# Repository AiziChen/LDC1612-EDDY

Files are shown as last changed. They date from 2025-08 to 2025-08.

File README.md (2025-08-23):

# LDC1612 Eddy coil

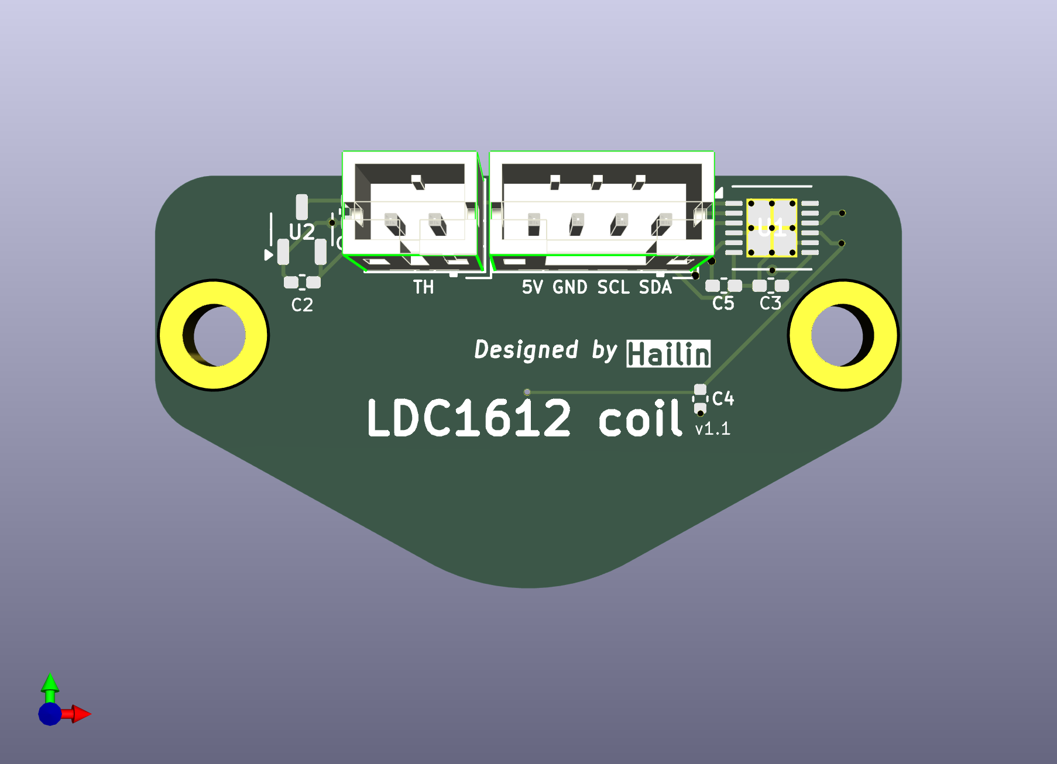
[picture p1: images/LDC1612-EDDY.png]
PCB foreground

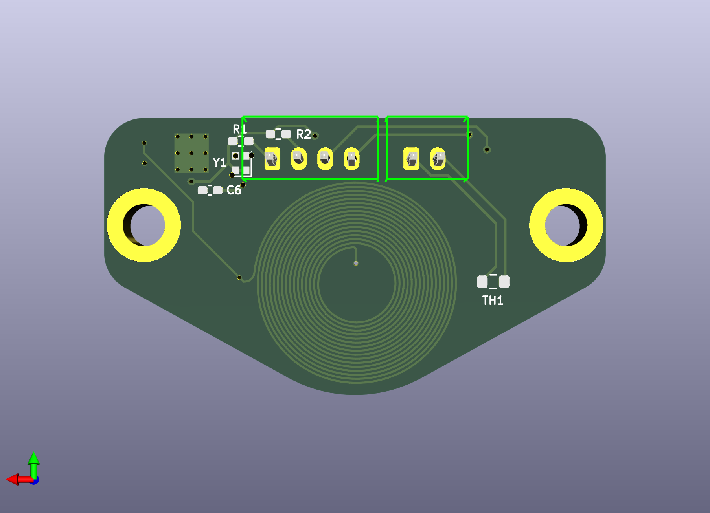
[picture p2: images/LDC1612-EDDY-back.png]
PCB background


A surface scanner for Klipper firmware [Eddy current probe](https://www.klipper3d.org/Eddy_Probe.html?h=eddy#eddy-current-inductive-probe) to provide very fast and high accuracy surface scanning.

## Features

* Similar to [Beacon revH](https://beacon3d.com/product/beacon-h/), but open source.
* Simple, no microcontroller, only LDC1612 chip inside.
* Connection stable, only support I2C connecting, but it is stable than via USB or CAN through an another MCU.
* Has an NTC thermistor to support coil temparature detect.

## How to use

This is a Kicad project, if you want to modify this project, you need to clone it, then download and install [Kicad](https://www.kicad.org/download/) to open.

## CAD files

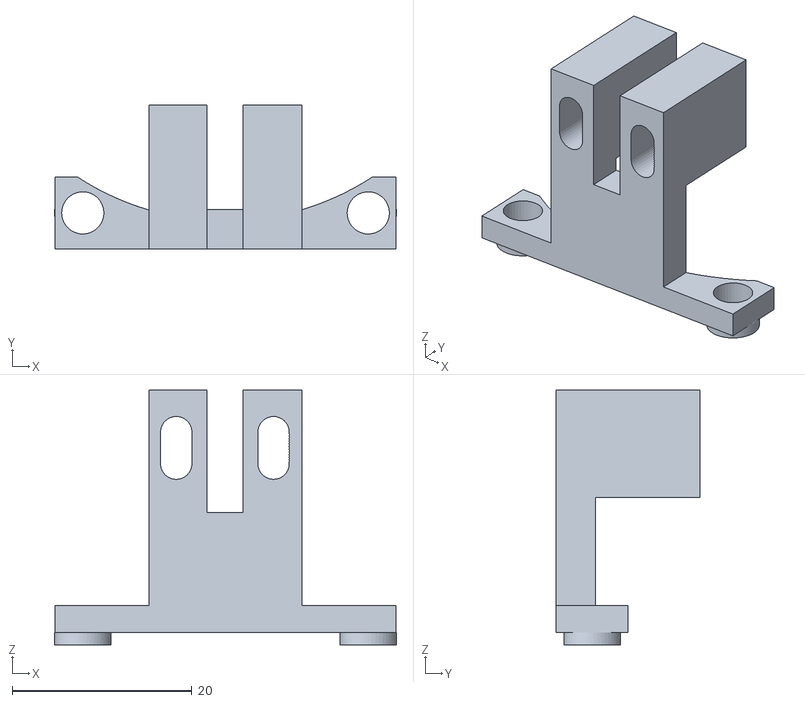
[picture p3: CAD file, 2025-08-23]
STL/LDC1612-eddy-coil-Mount [Voron-Carriage] - v1.0.2.stl
38.1 x 16.0 x 28.4

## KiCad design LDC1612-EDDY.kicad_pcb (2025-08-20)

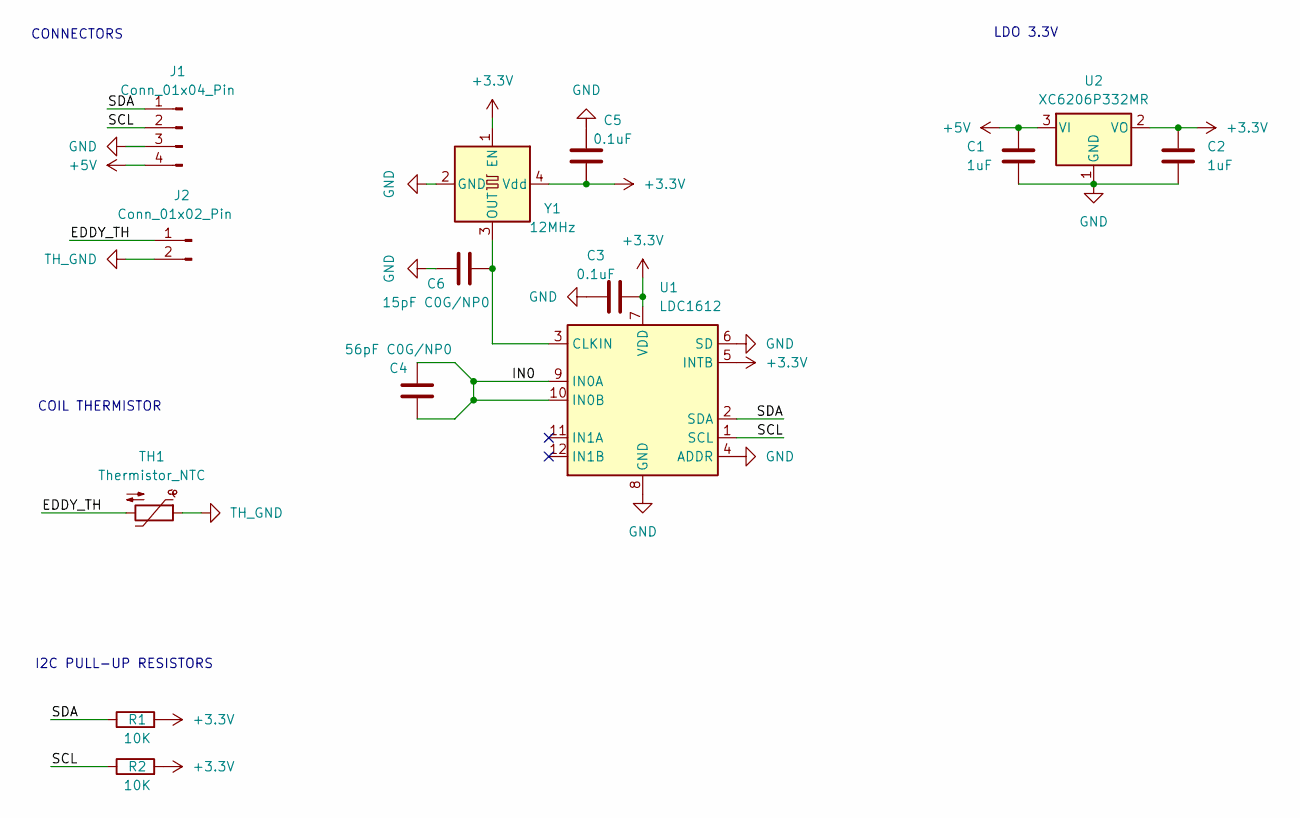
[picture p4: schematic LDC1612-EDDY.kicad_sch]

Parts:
C1, C2: 1uF; C_0402_1005Metric_Pad0.74x0.62mm_HandSolder
C3, C5: 0.1uF; C_0402_1005Metric_Pad0.74x0.62mm_HandSolder
C4: 56pF C0G/NP0; C_0402_1005Metric
C6: 15pF C0G/NP0; C_0402_1005Metric_Pad0.74x0.62mm_HandSolder
J1: Conn_01x04_Pin; JST_PH_B4B-PH-K_1x04_P2.00mm_Vertical
J2: Conn_01x02_Pin; JST_PH_B2B-PH-K_1x02_P2.00mm_Vertical
R1, R2: 10K; R_0402_1005Metric_Pad0.72x0.64mm_HandSolder
TH1: Thermistor_NTC; R_0603_1608Metric
U1: LDC1612; WSON-12-1EP_4x4mm_P0.5mm_EP2.6x3mm_ThermalVias
U2: XC6206P332MR; SOT-23-3
Y1: 12MHz; Oscillator_SMD_Abracon_ASCO-4Pin_1.6x1.2mm

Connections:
+3.3V: C2.1, C3.2, C5.1, R1.2, R2.2, U1.5 (INTB), U1.7 (VDD), U2.2 (VO), Y1.1 (EN), Y1.4 (Vdd)
+5V: C1.1, J1.4, U2.3 (VI)
/EDDY_TH: J2.1, TH1.2
/IN0: C4.1, C4.2, U1.9 (IN0A), U1.10 (IN0B)
/SCL: J1.2, R2.1, U1.1 (SCL)
/SDA: J1.1, R1.1, U1.2 (SDA)
GND: C1.2, C2.2, C3.1, C5.2, C6.2, J1.3, U1.4 (ADDR), U1.6 (SD), U1.8 (GND), U1.13 (GND), U2.1 (GND), Y1.2 (GND)
unnamed: C6.1, U1.3 (CLKIN), Y1.3 (OUT)
TH_GND: J2.2, TH1.1

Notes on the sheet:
LDO 3.3V
CONNECTORS
COIL THERMISTOR
I2C PULL-UP RESISTORS

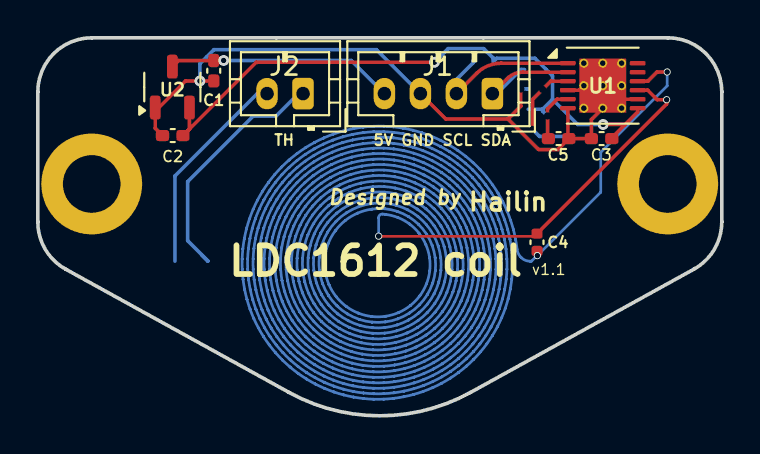
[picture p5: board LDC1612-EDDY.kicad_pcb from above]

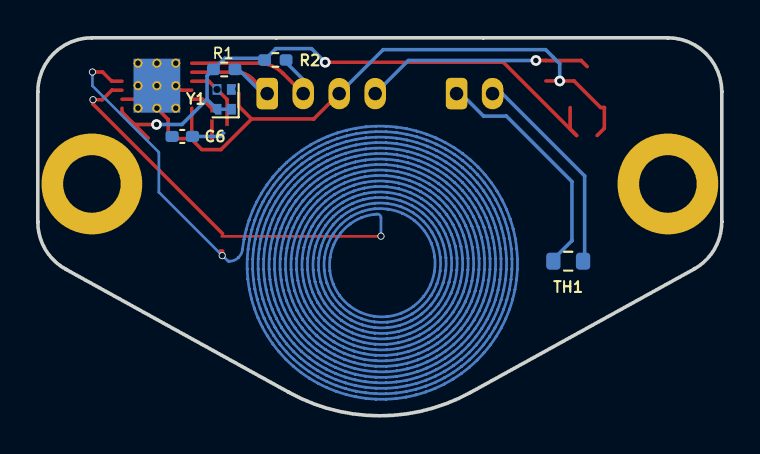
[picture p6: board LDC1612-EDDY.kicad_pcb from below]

Board: 2 copper layers, 38.0 x 21.0 mm, 14 parts (5 on the bottom side), 9 nets.

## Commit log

2025-08-18 Schematic: add pull-up resistors for I2C SDA & SCL also make groups for different sections
    [LDC1612-EDDY.kicad_sch]
2025-08-18 PCB: bump version to v1.02 * add pull-up resistors for SDA & SCL * change board name to `LDC1612 coil`
    [LDC1612-EDDY.kicad_pcb]
2025-08-20 Schematic & PCB: bump version to v1.1 * added an 12MHz external oscillator * fixed LDC1612 GND pin does not connected
    [LDC1612-EDDY.kicad_pcb, LDC1612-EDDY.kicad_sch]
2025-08-21 mod: add a STL mount for Voron carriage
    [LDC1612-eddy-coil-Mount [Voron-Carriage] - v1.0.stl]
2025-08-23 update mount carriage
    update images
    [LDC1612-eddy-coil-Mount [Voron-Carriage] - v1.0.1.stl]
2025-08-23 update mount for carriage
    [LDC1612-eddy-coil-Mount [Voron-Carriage] - v1.0.1.stl, LDC1612-eddy-coil-Mount [Voron-Carriage] - v1.0.2.stl, LDC1612-eddy-coil-Mount [Voron-Carriage] - v1.0.s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]
